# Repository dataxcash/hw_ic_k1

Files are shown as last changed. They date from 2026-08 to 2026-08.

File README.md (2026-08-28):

# hw_ic_k1 — K1 Master Gate Card (PCIe 2.1 x2 Injection)

Open-source hardware — KiCad design files for the **K1 Master Gate Card**,
the master-side converter card in the IOCONVERT V2.0 1-Master-to-4-Worker
chained NTB cluster.

## Overview

K1 sits at the **master side** of a PCIe NTB chain. It provides USB Type-C
management access, pre-authentication gating (SE050 via I2C), and a PCIe
2.1 x2 data path injected into the master host through an OCuLink connector.

```
KEY (secure vault) ──Type-C──► K1 Master Gate Card ──OCuLink──► Master Host
                                  │
                                  ├─ USB management (SBU I2C ↔ SE050 pre-auth)
                                  ├─ PCIe 2.1 x2 lane injection
                                  └─ 5V pre-auth power rail (TLV61046 boost)
```

## Key Features

- **Form factor**: 80 × 38 mm, 4-layer PCB
- **Interface**: USB Type-C (KEY), OCuLink SFF-8612 (host), 12V DC-in
- **Security**: STM32G0B1 MCU gatekeeper + SE050 pre-authentication via SBU I2C
- **Data path**: PCIe 2.1 x2 with PI3DBS16412 lane-swap MUX
- **Power**: 3.3V_AUX → 5V boost (TLV61046), LDO 5V→3V3, 12V→3V3 DC-DC
- **Management**: OOB UART passthrough, opto-isolated power button (LTV-356T)

## Repository Contents

| Path | Description |
|---|---|
| `k1_v1.kicad_pro` / `.kicad_pcb` | KiCad 10 project + PCB (self-contained) |
| `sch/` | Schematics: connectors, MCU & sideband, power (12V/5V/3V3), decoupling |
| `lib/IOCONVERT.kicad_sym` | Symbol library (80 symbols) — required for schematics |
| `lib/ForgeOS.pretty/` | Footprint library (19 footprints) |
| `boards/` | Board/nets configuration (YAML) |

## Getting Started

1. Install [KiCad](https://www.kicad.org/) 10.x
2. Clone this repository
3. Open `k1_v1.kicad_pro`
4. If symbols/footprints show as missing, add `lib/IOCONVERT.kicad_sym`
   to the symbol library table and `lib/ForgeOS.pretty/` to the footprint
   library table (global or project-level)

## License

AGPL-3.0 (see `LICENSE`)

---

*Part of the IOCONVERT V2.0 family: [hw_ic_k2](https://github.com/dataxcash/hw_ic_k2) (worker data-plane card) · [hw_ic_key](https://github.com/dataxcash/hw_ic_key) (secure key vault)*

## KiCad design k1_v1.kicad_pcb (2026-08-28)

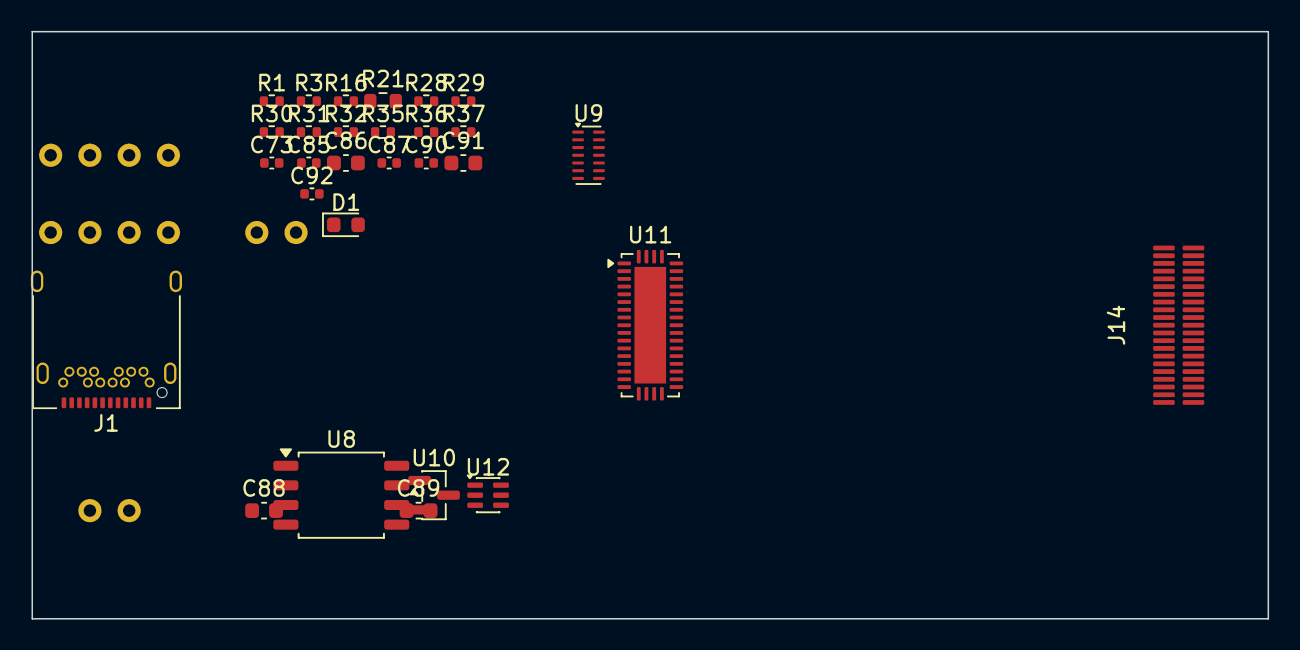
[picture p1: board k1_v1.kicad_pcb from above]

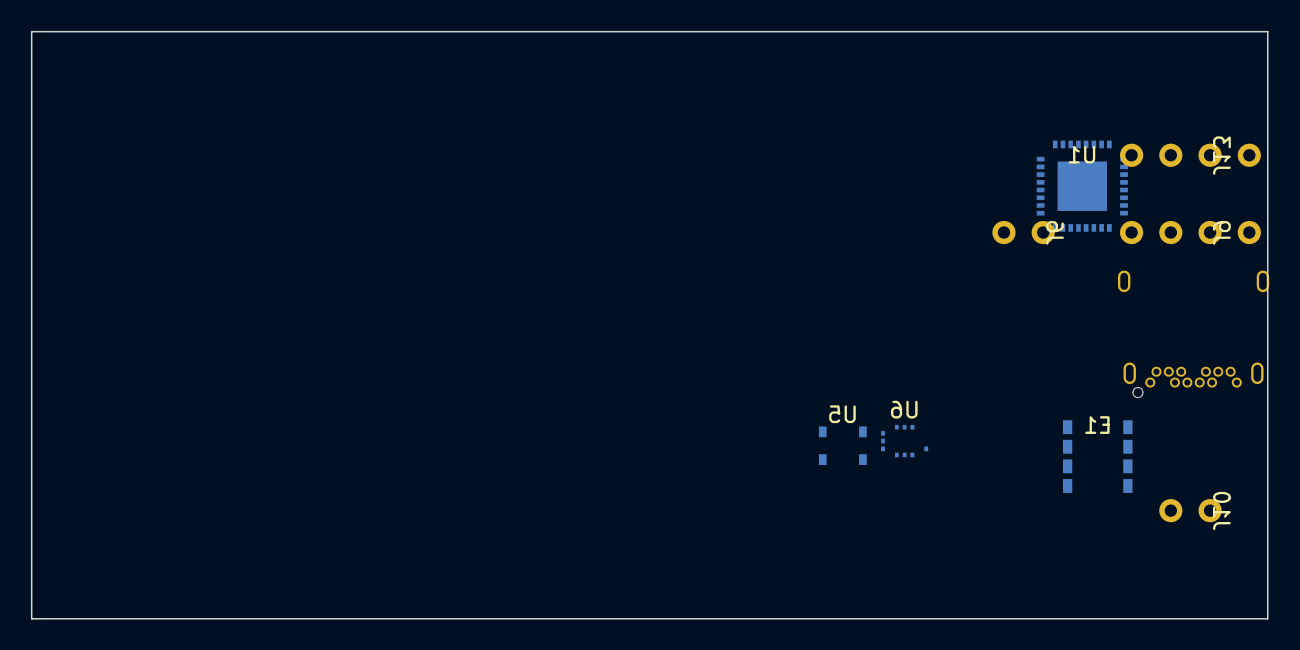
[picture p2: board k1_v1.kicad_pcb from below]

Board: 4 copper layers, 80.0 x 38.0 mm, 37 parts (8 on the bottom side), 47 nets, no tracks yet.

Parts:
C73, C85, C87, C90, C92: C_0402_1005Metric
C86, C88, C89, C91: C_0603_1608Metric
D1: LED_0603_1608Metric
E1: SOIC8_FRU
J1: USB_C_Receptacle_Amphenol_12401548E4-2A
J6, J10: PinHeader_1x02
J9, J13: PinHeader_1x04
J14: OCuLink_SFF8612
R1, R3, R16, R28, R29, R30, R31, R32, R35, R36, R37: R_0402_1005Metric
R21: R_0603_1608Metric
U1: MCU_STM32G0_QFN32
U5: OPTO_LTV356T
U6: TS3USB221A_UQFN10
U8: SOIC-8_5.3x5.3mm_P1.27mm
U9: TPD6E05U06_RVZ
U10: SOT-23
U11: PI3DBS16412
U12: TPS22919

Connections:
12V_IN: C88.1, J10.1, U8.4, U8.6
CC1: J1.A5, R35.2
CC2: J1.B5, R36.2
GND: C73.2, C85.2, C86.2, C87.2, C88.2, C89.2, C90.2, C91.2, C92.2, D1.2, E1.1, E1.4, J1.A1, J1.A12, J1.B1, J1.B12, J6.2, J10.2, J14.A2, J14.A5, J14.A8, J14.A11, J14.A13, J14.A14, J14.A17, J14.A20, J14.B2, J14.B5, J14.B8, J14.B11, J14.B14, J14.B17, J14.B20, R16.2, R28.2, R37.2, U1.8, U1.22, U1.32, U5.4, U6.1, U8.2, U9.13, U9.14, U11.4, U11.14, U11.19, U11.21, U11.39, U11.41, U11.CP, U12.2
GPIO_LED: R21.1, U1.24
I2C1_SCL: E1.5, R31.1, U1.11, U6.2
I2C1_SDA: E1.6, R32.1, U1.12, U6.3
KEY_D_N: J1.A7, U9.2
KEY_D_P: J1.A6, U9.1
LED_A: D1.1, R21.2
MCU_VDD: C85.1, C86.1, E1.8, R29.2, R30.2, R31.2, R32.2, U1.21
MUX_PD: U1.14, U11.1, U11.10
MUX_SEL: U1.15, U11.8, U11.17
NC: U11.18, U11.42
NRST: C73.1, R29.1, U1.1
OCuLink_RX0_N: J14.B4, U11.31
OCuLink_RX0_P: J14.B3, U11.32
OCuLink_RX1_N: J14.B7, U11.22
OCuLink_RX1_P: J14.B6, U11.23
OCuLink_TX0_N: J14.A4, U11.33
OCuLink_TX0_P: J14.A3, U11.34
OCuLink_TX1_N: J14.A7, U11.24
OCuLink_TX1_P: J14.A6, U11.25
P3V3_AUX: C90.1, C91.1, R1.2, R30.1, U1.7, U6.10, U11.5, U11.9, U11.13, U11.20, U11.30, U11.40
PCIE_RX0_N: J1.B10, U9.6, U11.7
PCIE_RX0_P: J1.B11, U9.5, U11.6
PCIE_RX1_N: J1.A10, U11.16
PCIE_RX1_P: J1.A11, U11.15
PCIE_TX0_N: J1.A2, U9.4, U11.3
PCIE_TX0_P: J1.A3, U9.3, U11.2
PCIE_TX1_N: J1.B2, U11.12
PCIE_TX1_P: J1.B3, U11.11
PERSTA#: C87.1, R1.1, U1.4
PWR_5V_KEY: C89.1, U8.5, U12.1
PWR_5V_PREAUTH: C92.1, J1.A4, J1.A9, J1.B4, J1.B9, R35.1, R36.1, U12.6
PWR_BTN_ISO: R3.2, U5.1, U5.2
PWR_BTN_OUT: R3.1, U1.23
PWR_CTRL_OUT: J6.1, U5.3
SBU1: J1.A8, R37.1, U1.17, U6.4
SBU2: J1.B8, U6.5
SBU_EN: U1.31, U6.9
SBU_SEL: R16.1, U1.6, U6.8
SWCLK_BOOT0: J13.1, R28.1, U1.20
SWDIO: J13.2, U1.19
TPS_EN: U1.26, U12.3
UART_RX: J9.2, U1.18
UART_TX: J9.1, U1.13

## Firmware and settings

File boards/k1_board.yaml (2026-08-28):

# ==============================================================================
# K1 卡 (Master 门禁卡) — 板级真源 (board truth source)
#
# 文件:     revA/boards/k1_board.yaml
# 任务:     k1-l1-bid-infra T1 — k1_board.yaml 真源构建 + 器件 refdes 对账
# 日期:     2026-08-21
# 权威:     revA/boards/k1_nets.yaml (refdes/net 权威, J14/U11/U6)
#           revA/sch_k1/*.kicad_sch (器件实例/符号/引脚数)
#           revA/pcb/export/ForgeOS.pretty/*.kicad_mod (footprint 实测 bbox)
#           AppDir KiCad 标准库 footprint (实测 bbox)
# 运行环境: 普通 python3 (无 pcbnew 依赖)
# 覆盖检查: revA/boards/k1_coverage_check.py
#
# refdes 命名: 以 k1_nets.yaml 为准 (J14=OCuLink, U11=PI3DBS16412, U6=TS3USB221A)。
#   README 概念名仅存注释: J_OCULINK=J14, U_PI3=U11, U_TPS=U12。
# 几何事实来源: geometry.source ∈ {footprint, datasheet, estimated}; 估算必带
#   estimated:true + 理由 (防逃逸预算虚高)。bbox 单位 mm, 全部来自 kicad_mod 实测。
# ==============================================================================
board:
  name: K1 (Master gate card, IOCONVERT V2.0 转换卡 1)
  card: K1
  dimension_mm:
  - 80
  - 38
  layers: 4
  card_type: Master 门禁卡 (PCIe 2.1 x2 注入 + 预鉴权)
  fixed_constraints:
  - 板框 80×38mm 4 层
  - 'J1 Type-C 卧式左缘 (horizontal, edge: left)'
  - 'J14 OCuLink 立式右缘 (vertical, edge: right)'
  - '无 ReDriver、无 AC 电容墙 (ECO31 补充说明: PCIe 2.0/2.1 5GT/s 短距直连, 不做均衡放大)'
  - K1/KEY 双公头线缆 (Mode B); Mode A 下 KEY 直插 PC, K1 不参与 (J7 已移除)
  l1_bid:
    strategy_type: mux_segmentation
    axes:
      mux_position:
      - center
      - near_j1
      - near_oculink
      power_island:
      - left
      - right
      mcu_partition:
      - independent
      - with_power
      - with_interface
  process:
    line_width_min_mm: 0.09
    spacing_min_mm: 0.1
    edge_clearance_min_mm: 0.3
    annular_ring_min_mm: 0.075
    stackup: 4 层 (F.Cu / In1 / In2 / B.Cu) — 叠层分配待 L2, 板厂确认档待定
devices:
  U1:
    value: STM32G0B1KBU6
    function: K1 MCU — 门禁鉴权 (SBU I2C Master 预鉴权) + MUX 切换 + 光耦开机 + OOB UART
    footprint: ForgeOS:MCU_STM32G0_QFN32
    sch_pins: 31
    fp_pads: 33
    geometry:
      bbox:
      - 5.9
      - 5.9
      pad_bbox:
      - 5.4
      - 5.4
      source: footprint
      provenance: revA/pcb/export/ForgeOS.pretty/MCU_STM32G0_QFN32.kicad_mod
    nets:
    - I2C1_SCL
    - I2C1_SDA
    - PERSTA#
    - PWR_BTN_OUT
    - GPIO_LED
    - UART_TX
    - UART_RX
    - P3V3_AUX
    - MCU_VDD
    - GND
    - NRST
    - SWCLK_BOOT0
    - SWDIO
    - SBU_SEL
    - SBU_EN
    - MUX_SEL
    - MUX_PD
    - TPS_EN
    - SBU1
  U11:
    value: PI3DBS16412
    function: 4 对差分 lane 翻转 MUX (K1 侧 Type-C 后端, ECO31 裁定 8) — README 概念名 U_PI3
    footprint: ForgeOS:PI3DBS16412
    sch_pins: 43
    fp_pads: 57
    geometry:
      bbox:
      - 5.1
      - 10.26
      pad_bbox:
      - 3.38
      - 8.88
      source: footprint
      provenance: revA/pcb/export/ForgeOS.pretty/PI3DBS16412.kicad_mod
      note: 42 信号 pad (1-42) + CP + 14 未编号; 计划参考 3.38×11.66 — 宽度一致, 长度以实测为准
    nets:
    - P3V3_AUX
    - GND
    - PCIE_TX0_P
    - PCIE_TX0_N
    - PCIE_RX0_P
    - PCIE_RX0_N
    - PCIE_TX1_P
    - PCIE_TX1_N
    - PCIE_RX1_P
    - PCIE_RX1_N
    - OCuLink_TX0_P
    - OCuLink_TX0_N
    - OCuLink_RX0_P
    - OCuLink_RX0_N
    - OCuLink_TX1_P
    - OCuLink_TX1_N
    - OCuLink_RX1_P
    - OCuLink_RX1_N
    - MUX_SEL
    - MUX_PD
  U6:
    value: TS3USB221A
    function: SBU 隔离开关候选 (I2C 预鉴权通道; B 通道 NC) — ECO31 裁定 3 / Open Item 4
    footprint: ForgeOS:TS3USB221A_UQFN10
    sch_pins: 10
    fp_pads: 10
    geometry:
      bbox:
      - 3.05
      - 2.1
      pad_bbox:
      - 2.8
      - 1.8
      source: footprint
      provenance: revA/pcb/export/ForgeOS.pretty/TS3USB221A_UQFN10.kicad_mod
    nets:
    - I2C1_SCL
    - I2C1_SDA
    - P3V3_AUX
    - GND
    - SBU_SEL
    - SBU_EN
    - SBU1
    - SBU2
  U8:
    value: DCDC_12V_5V
    function: 12V→5V DCDC (主电源)
    footprint: Package_SO:SOIC-8_5.3x5.3mm_P1.27mm
    sch_pins: 6
    fp_pads: 8
    geometry:
      bbox:
      - 9.3
      - 5.87
      pad_bbox:
      - 7.17
      - 3.81
      source: footprint
      provenance: AppDir/usr/share/kicad/footprints/Package_SO.pretty/SOIC-8_5.3x5.3mm_P1.27mm.kicad_mod
    nets:
    - 12V_IN
    - GND
    - PWR_5V_KEY
  U10:
    value: LDO_5V_3V3
    function: 5V→3V3 LDO (P3V3_AUX 轨)
    footprint: Package_TO_SOT_SMD:SOT-23
    sch_pins: 5
    fp_pads: 3
    geometry:
      bbox:
      - 3.86
      - 3.4
      source: footprint
      provenance: AppDir/usr/share/kicad/footprints/Package_TO_SOT_SMD.pretty/SOT-23.kicad_mod
      estimated: true
      note: 符号 5 pin vs SOT-23 3 pad 不匹配 (reconciliation OPEN-2); 实际器件应为 SOT-23-5 (实测 bbox 4.10×3.54), 布局预算按 SOT-23-5 取
    nets:
    - P3V3_AUX
    - MCU_VDD
    - GND
    - PWR_5V_KEY
  U12:
    value: TPS22919
    function: 预鉴权供电软启动 Load Switch (裁定 7) — README 概念名 U_TPS
    footprint: ForgeOS:TPS22919
    sch_pins: 6
    fp_pads: 6
    geometry:
      bbox:
      - 2.9
      - 2.39
      pad_bbox:
      - 1.68
      - 1.3
      source: footprint
      provenance: revA/pcb/export/ForgeOS.pretty/TPS22919.kicad_mod
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

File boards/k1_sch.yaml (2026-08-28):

symbols:
- name: MCIO_4i
  ref_prefix: J
  value: MCIO_4i_SFF1016
  footprint: ForgeOS:MCIO_4i_SFF-1016_RASide
  body_width: 19.8
  pin_pitch: 2.54
  pins:
    right:
    - - TX0_P
      - 4
      - OUTPUT
      - DIFF_PAIR_TX
    - - TX0_N
      - 6
      - OUTPUT
      - DIFF_PAIR_TX
    - - TX1_P
      - 10
      - OUTPUT
      - DIFF_PAIR_TX
    - - TX1_N
      - 12
      - OUTPUT
      - DIFF_PAIR_TX
    - - TX2_P
      - 28
      - OUTPUT
      - DIFF_PAIR_TX
    - - TX2_N
      - 30
      - OUTPUT
      - DIFF_PAIR_TX
    - - TX3_P
      - 34
      - OUTPUT
      - DIFF_PAIR_TX
    - - TX3_N
      - 36
      - OUTPUT
      - DIFF_PAIR_TX
    - - RX0_P
      - 3
      - PASSIVE
      - DIFF_PAIR_RX
    - - RX0_N
      - 5
      - PASSIVE
      - DIFF_PAIR_RX
    - - RX1_P
      - 9
      - PASSIVE
      - DIFF_PAIR_RX
    - - RX1_N
      - 11
      - PASSIVE
      - DIFF_PAIR_RX
    - - RX2_P
      - 27
      - PASSIVE
      - DIFF_PAIR_RX
    - - RX2_N
      - 29
      - PASSIVE
      - DIFF_PAIR_RX
    - - RX3_P
      - 33
      - PASSIVE
      - DIFF_PAIR_RX
    - - RX3_N
      - 35
      - PASSIVE
      - DIFF_PAIR_RX
    - - REFCLK_P
      - 21
      - BIDIR
      - CLOCK
    - - REFCLK_N
      - 23
      - BIDIR
      - CLOCK
    - - FLEXIO_0A
      - '15'
      - BIDIR
      - SIDEBAND
    - - CBL_PRES#
      - '24'
      - INPUT
      - SIDEBAND
    left:
    - - P3V3_AUX
      - '17'
      - PASSIVE
      - POWER_GND
    - - PERST#
      - 22
      - INPUT
      - SIDEBAND
    - - SMB_CLK
      - 16
      - BIDIR
      - SIDEBAND
    - - SMB_DATA
      - 18
      - BIDIR
      - SIDEBAND
    - - GND
      - 1
      - PASSIVE
      - POWER_GND
    - - GND
      - 2
      - PASSIVE
      - POWER_GND
    - - GND
      - 7
      - PASSIVE
      - POWER_GND
    - - GND
      - 8
      - PASSIVE
      - POWER_GND
    - - GND
      - 13
      - PASSIVE
      - POWER_GND
    - - GND
      - 14
      - PASSIVE
      - POWER_GND
    - - GND
      - 19
      - PASSIVE
      - POWER_GND
    - - GND
      - 20
      - PASSIVE
      - POWER_GND
    - - GND
      - 25
      - PASSIVE
      - POWER_GND
    - - GND
      - 26
      - PASSIVE
      - POWER_GND
    - - GND
      - 31
      - PASSIVE
      - POWER_GND
    - - GND
      - 32
      - PASSIVE
      - POWER_GND
    - - GND
      - 37
      - PASSIVE
      - POWER_GND
    - - GND
      - 38
      - PASSIVE
      - POWER_GND
  card: '2'
- name: SlimSAS_x8
  ref_prefix: J
  value: SlimSAS_x8_SFF8654
  footprint: ForgeOS:SlimSAS_x8_SFF-8654_74pin_RASide
  body_width: 23.3
  pin_pitch: 2.54
  pins:
    right:
    - - GND
      - 1
      - PASSIVE
      - POWER_GND
    - - RX0_P
      - 2
      - PASSIVE
      - DIFF_PAIR_RX
    - - RX0_N
      - 3
      - PASSIVE
      - DIFF_PAIR_RX
    - - GND
      - 4
      - PASSIVE
      - POWER_GND
    - - RX1_P
      - 5
      - PASSIVE
      - DIFF_PAIR_RX
    - - RX1_N
      - 6
      - PASSIVE
      - DIFF_PAIR_RX
    - - GND
      - 7
      - PASSIVE
      - POWER_GND
    - - GND
      - 8
      - PASSIVE
      - POWER_GND
    - - GND
      - 9
      - PASSIVE
      - POWER_GND
    - - GND
      - 10
      - PASSIVE
      - POWER_GND
    - - REFCLK0_P
      - 11
      - BIDIR
      - CLOCK
    - - REFCLK0_N
      - 12
      - BIDIR
      - CLOCK
    - - GND
      - 13
      - PASSIVE
      - POWER_GND
    - - RX2_P
      - 14
      - PASSIVE
      - DIFF_PAIR_RX
    - - RX2_N
      - 15
      - PASSIVE
      - DIFF_PAIR_RX
    - - GND
      - 16
      - PASSIVE
      - POWER_GND
    - - RX3_P
      - 17
      - PASSIVE
      - DIFF_PAIR_RX
    - - RX3_N
      - 18
      - PASSIVE
      - DIFF_PAIR_RX
    - - GND
      - 19
      - PASSIVE
      - POWER_GND
    - - RX4_P
      - 20
      - PASSIVE
      - DIFF_PAIR_RX
    - - RX4_N
      - 21
      - PASSIVE
      - DIFF_PAIR_RX
    - - GND
      - 22
      - PASSIVE
      - POWER_GND
    - - RX5_P
      - 23
      - PASSIVE
      - DIFF_PAIR_RX
    - - RX5_N
      - 24
      - PASSIVE
      - DIFF_PAIR_RX
    - - GND
      - 25
      - PASSIVE
      - POWER_GND
    - - GND
      - 26
      - PASSIVE
      - POWER_GND
    - - GND
      - 27
      - PASSIVE
      - POWER_GND
    - - GND
      - 28
      - PASSIVE
      - POWER_GND
    - - REFCLK1_P
      - 29
      - BIDIR
      - CLOCK
    - - REFCLK1_N
      - 30
      - BIDIR
      - CLOCK
    - - GND
      - 31
      - PASSIVE
      - POWER_GND
    - - RX6_P
      - 32
      - PASSIVE
      - DIFF_PAIR_RX
    - - RX6_N
      - 33
      - PASSIVE
      - DIFF_PAIR_RX
    - - GND
      - 34
      - PASSIVE
      - POWER_GND
    - - RX7_P
      - 35
      - PASSIVE
      - DIFF_PAIR_RX
    - - RX7_N
      - 36
      - PASSIVE
      - DIFF_PAIR_RX
    - - GND
      - 37
      - PASSIVE
      - POWER_GND
    left:
    - - GND
      - 38
      - PASSIVE
      - POWER_GND
    - - TX0_P
      - 39
      - OUTPUT
      - DIFF_PAIR_TX
    - - TX0_N
      - 40
      - OUTPUT
      - DIFF_PAIR_TX
    - - GND
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

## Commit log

2026-08-28 publish: k1 开源快照 (KiCad 工程/原理图/PCB/符号/封装/BOM)
    [k1_sch.kicad_sch, k1_v1.kicad_pcb, v5_connectors.kicad_sch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]
2026-09-15 chore: 补 AGPL-3.0 LICENSE 全文（README 写 'see LICENSE' 但文件缺失）
2026-10-21 docs: add final 4K 3D top render of completed K1 board to README
    ECN-14/15/16 complete: J1 Type-C re-mounted facing left edge (270°),
    15 high-speed nets re-routed and length-matched (skew <= 0.10 mm),
    H5 mounting hole added, 47 components / 5 holes verified.
    J1 body = Amphenol stand-in STEP; JAE DX07S024WJ1R350 pending.
    Owner-ordered README image update.
